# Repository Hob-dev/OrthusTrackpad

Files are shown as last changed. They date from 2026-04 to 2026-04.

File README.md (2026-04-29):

# OrthusTrackpad

A capacitive trackpad PCB designed as a component of the [Orthus](https://github.com/Hob-dev/Orthus) split keyboard, but also usable as a standalone mutual-capacitance touch sensor.

The PCB carries a diamond-pattern mutual-capacitance sensor grid intended to be paired with a touch controller IC and read over I²C. The grill cutout in `Fabrication/` matches the sensor pitch and is meant to be laser/CNC-cut from a thin overlay.

## Status

**Functionally complete.** Gerbers, BOM, and pick-and-place (CPL) files are all generated and present under `JLCPCB/`.

## Renders

| | | |
|---|---|---|
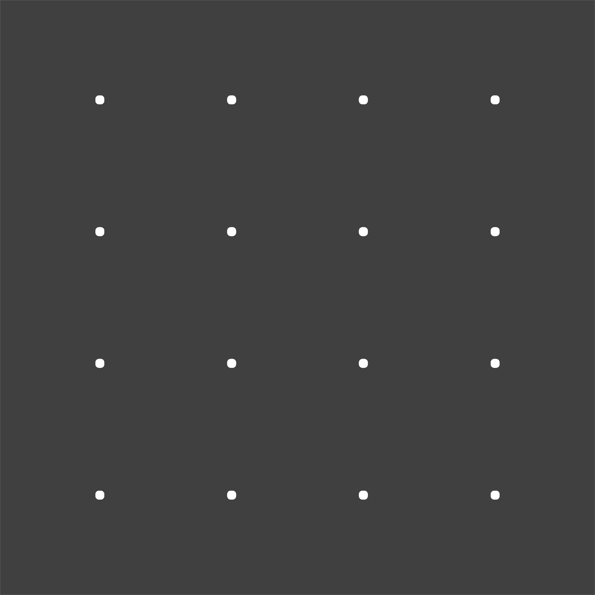
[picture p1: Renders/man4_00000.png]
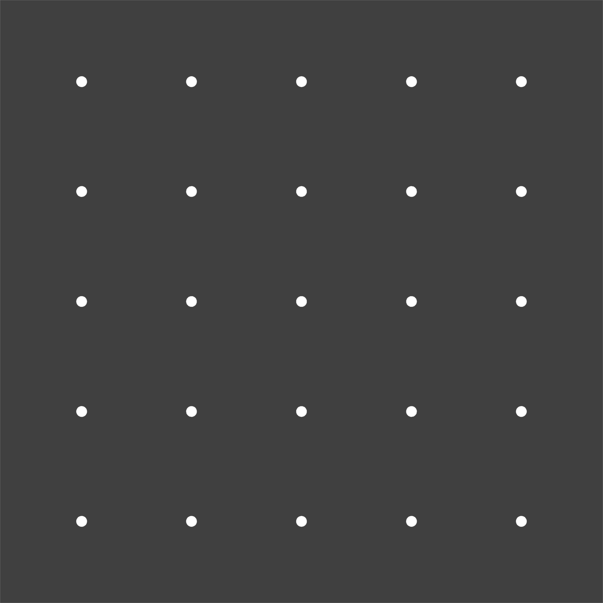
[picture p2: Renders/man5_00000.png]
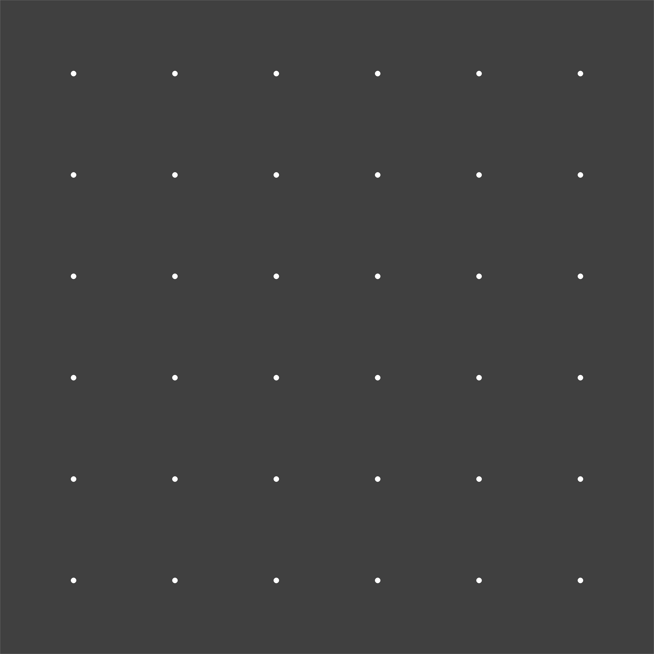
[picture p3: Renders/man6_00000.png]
|  |  |  |

*Note: the renders are PCB-only views with the silkscreen and sensor traces on a white background; the geometry is faint at fit-to-screen zoom. Open the PNGs locally or load `KiCad/OrthusTrackpad.kicad_pcb` in KiCad's 3D viewer for a clearer view.*

## Folder layout

```
OrthusTrackpad/
├── KiCad/              KiCad 7+ project — open OrthusTrackpad.kicad_pro
│   ├── OrthusTrackpad.kicad_pcb     Board layout (sensor grid + routing)
│   ├── OrthusTrackpad.kicad_sch     Schematic
│   ├── fp-info-cache                KiCad footprint cache
│   └── backups/                     Dated KiCad auto-backups
├── Renders/            Sensor-grid PNG exports (man4/5/6_00000.png)
├── 3D/                 OrthusTrackpad.step — mechanical model of the PCB
├── Fabrication/        MutualCapSensorGride.dxf — sensor-grid overlay cutout
└── JLCPCB/             Production-ready output
    ├── gerber/                      Per-layer .gbr + .drl files (Cu/Mask/Silk top+bottom, NPTH/PTH drills)
    ├── production_files/            Ready-to-upload bundle:
    │                                  GERBER-OrthusTrackpad.zip
    │                                  BOM-OrthusTrackpad.csv
    │                                  CPL-OrthusTrackpad.csv
    └── project.db                   JLCPCB project metadata
```

## Relationship to Orthus

This PCB also lives inside the main Orthus repo at [`Orthus/Components/OrthusTrackpad/`](https://github.com/Hob-dev/Orthus/tree/main/Components/OrthusTrackpad). The two folders are independent copies — edits in one do **not** propagate to the other. Treat this standalone repo as the canonical version when iterating on the trackpad in isolation.

## Original source

All files were originally copied from `Custom/Ergomania/OrthusTrackpad/` in the local working tree; the original folder is preserved at that location.

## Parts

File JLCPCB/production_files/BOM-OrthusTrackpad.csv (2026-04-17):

Comment | Designator | Footprint | LCSC | Quantity
100nF | C7 | C_0402_1005Metric | C1525 | 1
100pF | C1,C3,C5 | C_0402_1005Metric | C1546 | 3
IQS7211E001QNR | U1 | UQFN-20_L3.0-W3.0-P0.40-BL-EP1.7 | C20179547 | 1
4.7k | R1,R2,R3 | R_0603_1608Metric | C23162 | 3
Conn_01x06 | J1 | FPC-SMD_6P-P0.50_XUNPU_FPC-05F-6PH15 | C2856814 | 1
2.2uF | C2,C4,C6 | C_0402_1005Metric | C60078 | 3

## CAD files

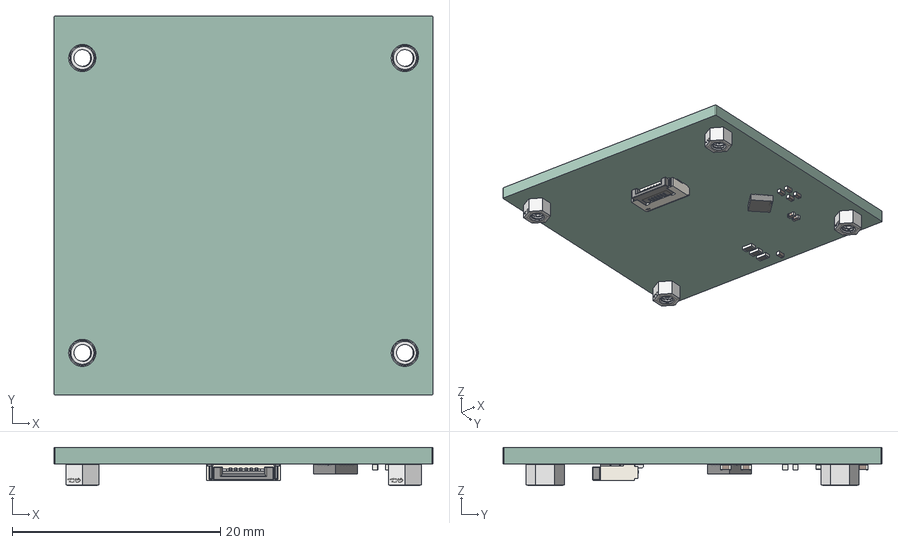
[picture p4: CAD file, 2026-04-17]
3D/OrthusTrackpad.step
36.4 x 36.4 x 3.65 mm
C_0402_1005Metric x 7
SMD-1_SMTSO1620MTJ x 4
R_0603_1608Metric x 3
UQFN-20_L3.0-W3.0-P0.40-BL-EP1.7
FPC-SMD_6P-P0.50_XUNPU_FPC-05F-6PH15
OrthusTrackpad_PCB

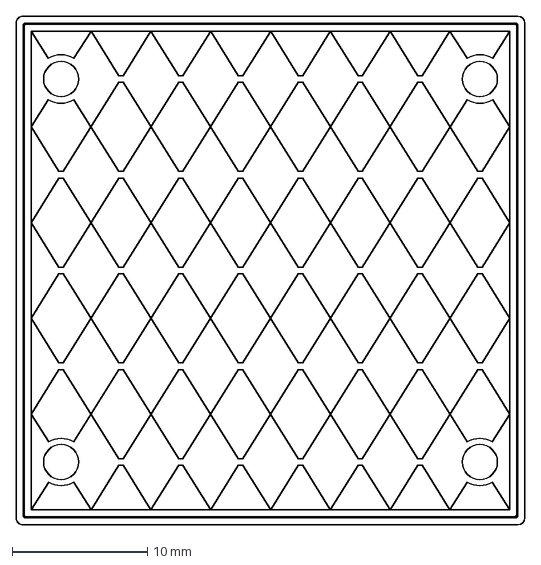
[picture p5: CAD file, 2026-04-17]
Fabrication/MutualCapSensorGride.dxf
37.6 x 37.6 mm

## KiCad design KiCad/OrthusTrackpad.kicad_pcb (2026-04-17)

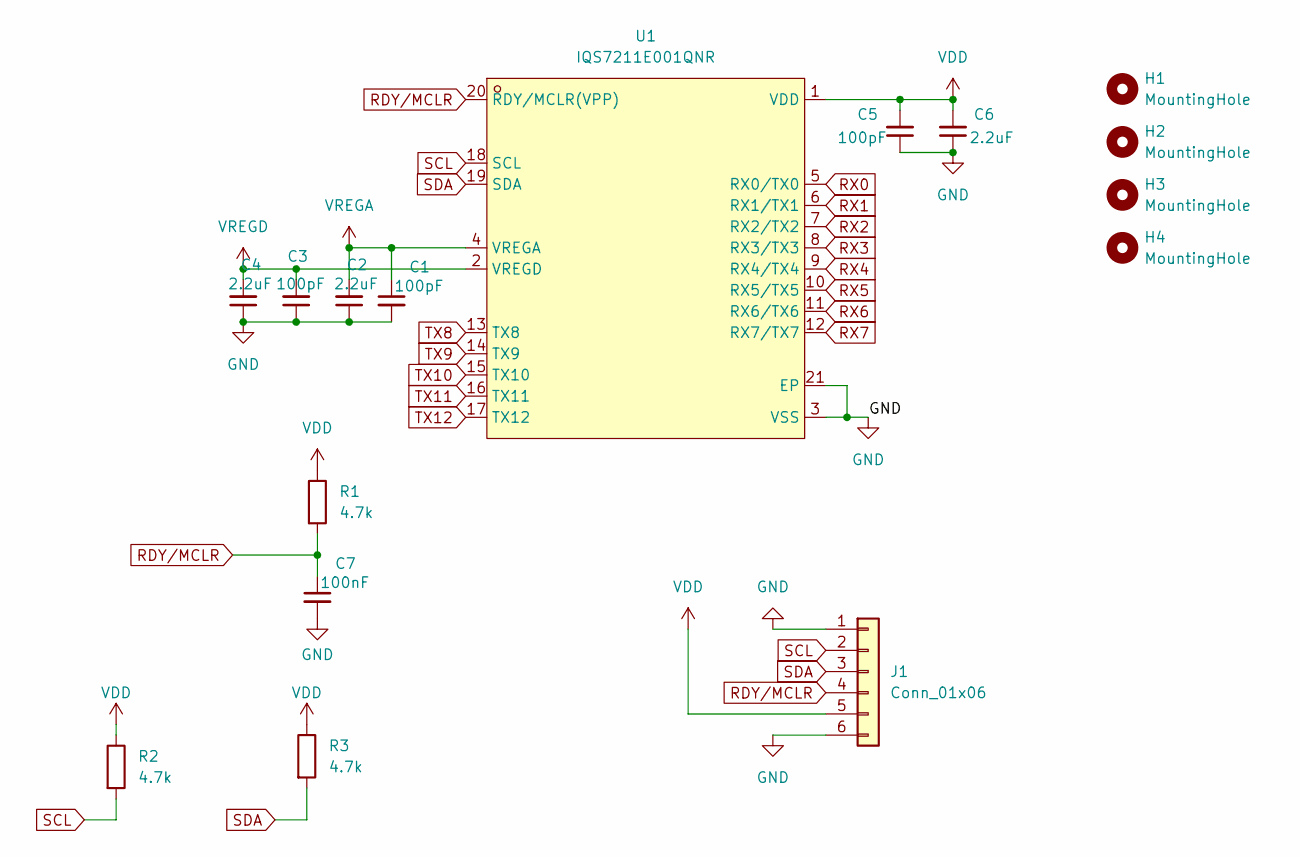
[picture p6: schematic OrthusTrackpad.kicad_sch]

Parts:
C1, C3, C5: 100pF; C_0402_1005Metric
C2, C4, C6: 2.2uF; C_0402_1005Metric
C7: 100nF; C_0402_1005Metric
H1, H2, H3, H4: MountingHole; SMD-1_SMTSO1620MTJ
J1: Conn_01x06; FPC-SMD_6P-P0.50_XUNPU_FPC-05F-6PH15
R1, R2, R3: 4.7k; R_0603_1608Metric
U1: IQS7211E001QNR; UQFN-20_L3.0-W3.0-P0.40-BL-EP1.7; LCSC Part C20179547

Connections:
GND: C1.2, C2.1, C3.1, C4.1, C5.1, C6.1, C7.2, J1.1, J1.6, U1.3 (VSS), U1.21 (EP)
RDY/MCLR: C7.1, J1.4, R1.2, U1.20 (RDY/MCLR(VPP))
RX0: U1.5 (RX0/TX0)
RX1: U1.6 (RX1/TX1)
RX2: U1.7 (RX2/TX2)
RX3: U1.8 (RX3/TX3)
RX4: U1.9 (RX4/TX4)
RX5: U1.10 (RX5/TX5)
RX6: U1.11 (RX6/TX6)
RX7: U1.12 (RX7/TX7)
SCL: J1.2, R2.2, U1.18 (SCL)
SDA: J1.3, R3.2, U1.19 (SDA)
TX8: U1.13 (TX8)
TX9: U1.14 (TX9)
TX10: U1.15 (TX10)
TX11: U1.16 (TX11)
TX12: U1.17 (TX12)
VDD: C5.2, C6.2, J1.5, R1.1, R2.1, R3.1, U1.1 (VDD)
VREGA: C1.1, C2.2, U1.4 (VREGA)
VREGD: C3.2, C4.2, U1.2 (VREGD)

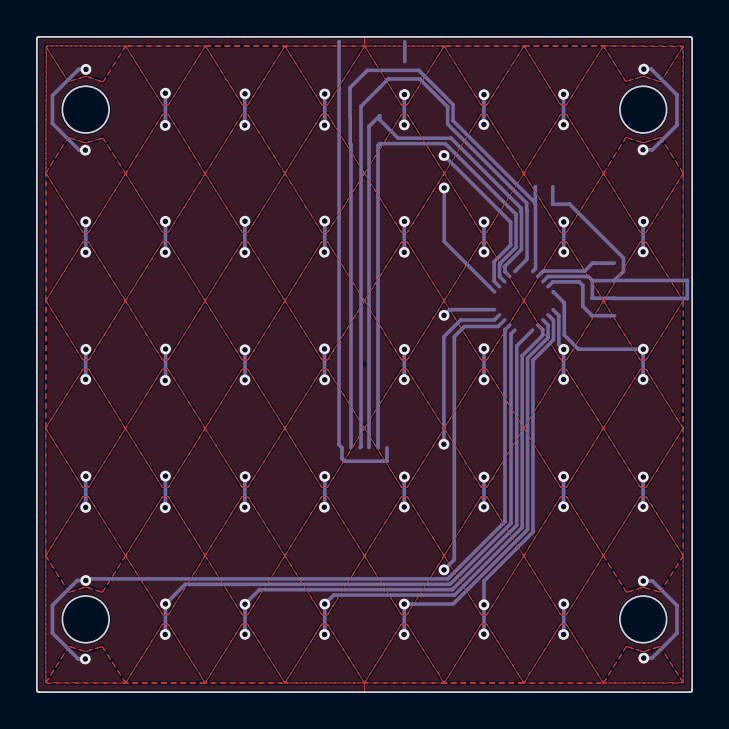
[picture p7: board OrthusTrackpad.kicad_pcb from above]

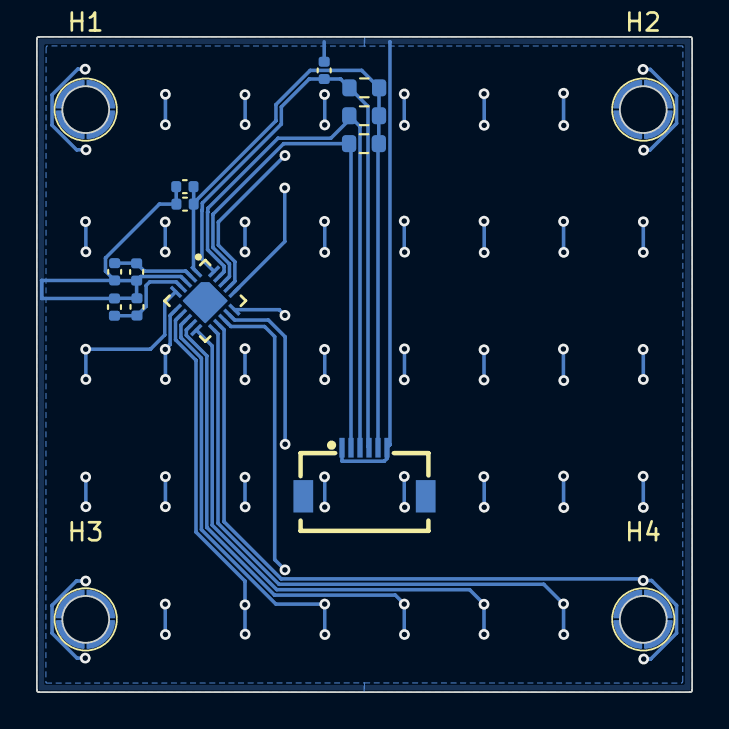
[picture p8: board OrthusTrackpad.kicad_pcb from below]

Board: 2 copper layers, 36.4 x 36.4 mm, 16 parts (16 on the bottom side), 7 nets.
